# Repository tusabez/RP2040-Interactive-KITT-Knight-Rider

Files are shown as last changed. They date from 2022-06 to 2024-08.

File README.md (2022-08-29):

# RP2040-Interactive-KITT-Knight-Rider
Create your own KITT from the TV show Knight Rider using an RP2040 Microcontroller  <br />
YouTube video preview  <br />
<div align="center">
  <a href="https://www.youtube.com/watch?v=hxRDTuXU2fs">IMAGE ALT TEXT</a>
</div>

## Introduction
Welcome to the tutorial to build your very own Interactive KITT from the TV show Knight Rider!  This will be divided into 3 parts.  Part 1 will explain the hardware and PCBs needed for the project. <br />
Part 2 will explain the code and software needed to install on your RP2040 microcontroller. <br />
Part 3 will explain the asthetics including 3D printing the body, creating the labels for the indicators, and using colored sheets for the voicebox and indicators. <br />

# Part 1 Hardware
For this project, you will need to order 2 different PCBs to create KITT.  The Gerber files needed to have them made are available in this repository.  You will need to upload these files (two files already in zip format) to your preferred PCB manufacturer.  I usually use JLBPCB as they tend to be the cheapest but feel free to use anyone. <br />
You will also find a PDF called Parts which you can download and view. I'm not affiliated with any of the links.  They are there for your reference. You'll need these parts to complete the PCBs.  Note that you should be comfortable in soldering as there are many components needed to be soldered onto the boards. Most of these parts can be ordered through websites like Adafruit, Amazon, Aliexpress, Mouser, etc... <br />
## Equipment
For equipment needed to build this part of the project, you'll need a soldering iron and stand, hot air gun, some shrink wrap for wires, wire cutters and wire stripper, solder, and solder paste. <br />
## Parts
One part that is required for this project but no longer manufactured by Adafruit is the UDA1334A DAC module.  However, you can find 3rd party versions of it on Amazon and Aliexpress. <br />
The PDM Mic used for this project is very sensitive and I had difficulty making it detect sound correctly.  If you have this issue, try disconnecting the VCC(power) from the board to the mic and run it that way.  That seems to fix the problem and I'm not sure why. <br />
Notice the connectors between the two boards are 2mm and not the standard 2.54mm.  I'd like to say this was intentional to save room but honestly it was a mistake I made in the original design but I decided to keep it as it does make the cables a little more compact. <br />
The RGB LEDs used for the indicator lights (Not the LED bars for KITT) are 5v versions.  Make sure you check before you buy as they also make them in 12v. (I ended up getting shipped the wrong voltage LEDs and it took me a few weeks of troubleshooting before I figured out why my LED board didn't work.) <br />
I chose the Waveshare RP-2040 Plus microcontroller because it has 4MB of memory.  However, you can use any rp2040 based microcontroller as long as it has (A) 4MB or more of flash memory and (B) it is in the same form factor as the original Raspberry Pi Pico.  If you decide to go with a different microcontroller, make sure the pins line up exactly as the Pico with the same GPIO assignments or it will not work. <br />
## Part 1 video
<div align="center">
  <a href="https://www.youtube.com/watch?v=F8oxOOc2xko">IMAGE ALT TEXT</a>
</div>

# Part 2 Programming and Software
Coming soon <br />
# Part 3 Aesthetics and 3D printing
Coming soon

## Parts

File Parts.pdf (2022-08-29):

# LED Board Quantity Notes and Links

I'm not affiliated nor compensated for any of these links. These are for reference only. I recommend you shop around for the best deals.
100nf smd capacitor | 17 | https://www.amazon.com/100pcs-0805-100nf-Multilayer-Ceramic-Capacitor/dp/B07P9D6W78
10 segment LED Bar Red | 6 | https://www.mouser.com/ProductDetail/Kingbright/DC10SRWA?qs=SxaZfIVsCL3oiC6rI9sPSQ%3D%3D
WS2812B RGB LEDs | 17 | https://www.amazon.com/Led-World-WS2812B-Individually-Addressable/dp/B00YC7ZXRM
2mm headers | 1 | https://www.adafruit.com/product/2671
180 Ohms resistor | 6 | https://www.amazon.com/Projects-Resistors-Watt-Choose-Quantity/dp/B077H1VK2Z
150 Ohms resistor | 2 | https://www.amazon.com/Projects-Resistors-Watt-Choose-Quantity/dp/B072F77NL5

# Driver Board

Waveshare RP2040-Plus | 1 | https://www.waveshare.com/rp2040-plus.htm
10uF Tan Capacitor | 2 | https://www.amazon.com/CAPACITOR-SOLID-TANTALUM-10UF-RADIAL/dp/B007Z7PJT8
10uF Capacitor | 1 | https://www.amazon.com/Projects-Radial-Electrolytic-Capacitor-10uF/dp/B07YBCF9NG
1N5817 Diode | 1 | https://www.amazon.com/1N5817-Axial-Leaded-Schottky-Rectifier/dp/B00I6IDW30
AMS1117-1.8 | 1 | https://www.amazon.com/AMS1117-1-8V-AMS1117-Voltage-Regulator-SOT-223/dp/B07Q3D77KT
UDA1334A DAC | 1 | https://www.amazon.com/AITRIP-CJMCU-1334-UDA1334A-Decoder-Arduino/dp/B09DG21C7G
LM3915N-1 | 1 | https://www.amazon.com/LM3915N-LM3915-Nixie-Display-Driver/dp/B0137JYL00
IR Sensor | 1 | https://www.amazon.com/dp/B09WB54YSM
PDM Mic | 1 | https://www.adafruit.com/product/3492
2mm headers | 1 | same as above
Speaker Amp | 1 | https://www.adafruit.com/product/2130
12V Jack | 1 | https://www.amazon.com/DIKAVS-Breadboard-friendly-2-1mm-Barrel-Jack/dp/B074LK7G86
Power switch | 1 | https://www.amazon.com/DaierTek-250VAC-Rocker-KCD1-101-Plastic/dp/B07S2QJKTX
BC557 Transistors | 10 | https://www.amazon.com/Eowpower-250PCS-Values-Transistors-Assortment/dp/B071P849QB
1k Ohms Resistors | 11 | https://www.amazon.com/EDGELEC-Resistor-Tolerance-Resistance-Optional/dp/B07HDDWFDD
TSR 2-2450 | 1 | https://www.tracopower.com/model/tsr-2-2450
Variable Resistor | 1 | https://www.amazon.com/10K-OHM-Trimpot-Variable-Resistor/dp/B00YSMMCOI

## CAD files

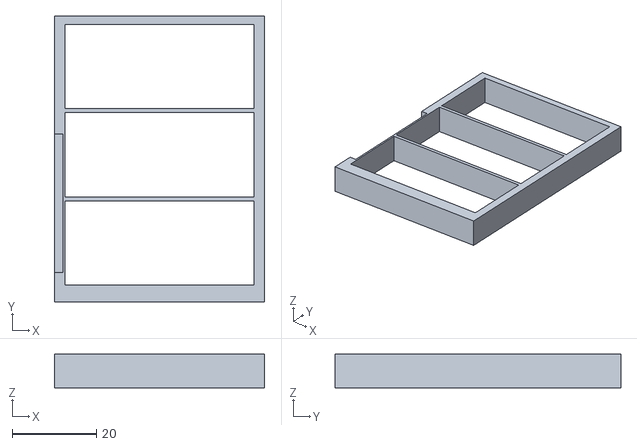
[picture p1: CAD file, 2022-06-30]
STLS/KITT Square Spacer v2.stl
50.0 x 68.0 x 8.00

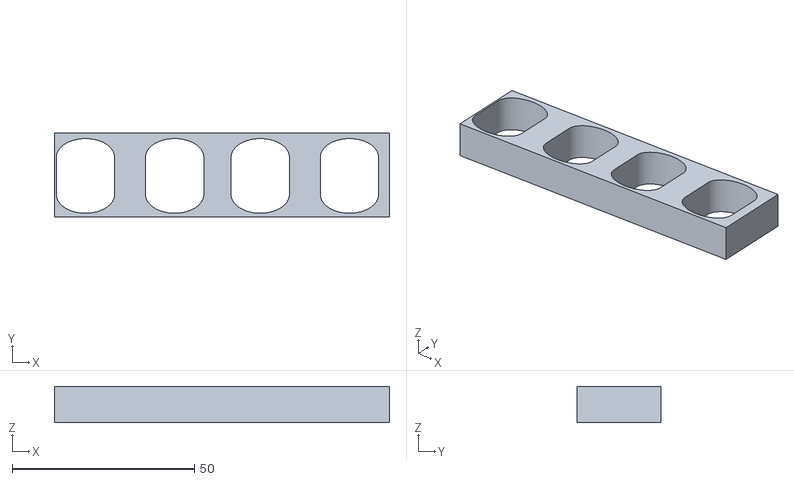
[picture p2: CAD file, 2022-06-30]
STLS/KITT Spacers x2.stl
92.0 x 23.0 x 10.00

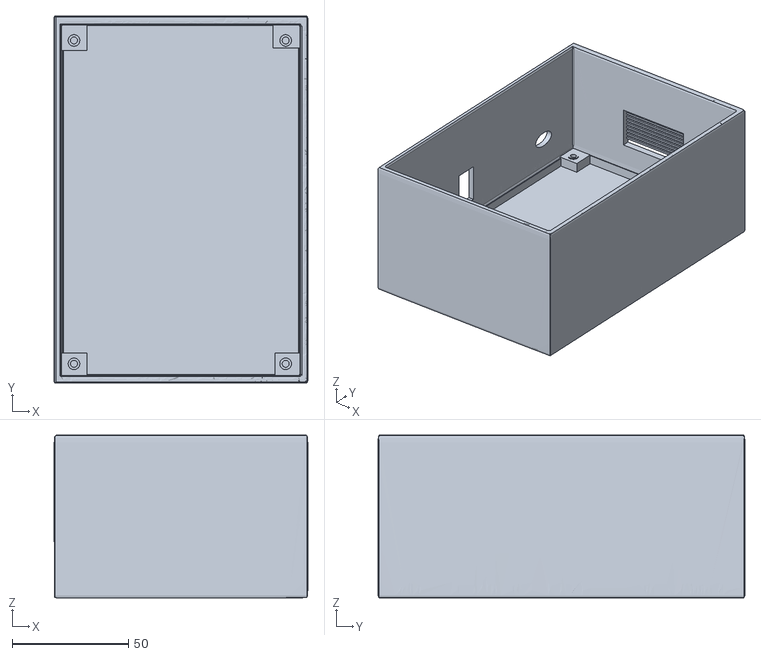
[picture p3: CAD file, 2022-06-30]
STLS/KITT Voice Box Backv3.stl
109.0 x 157.8 x 70.0

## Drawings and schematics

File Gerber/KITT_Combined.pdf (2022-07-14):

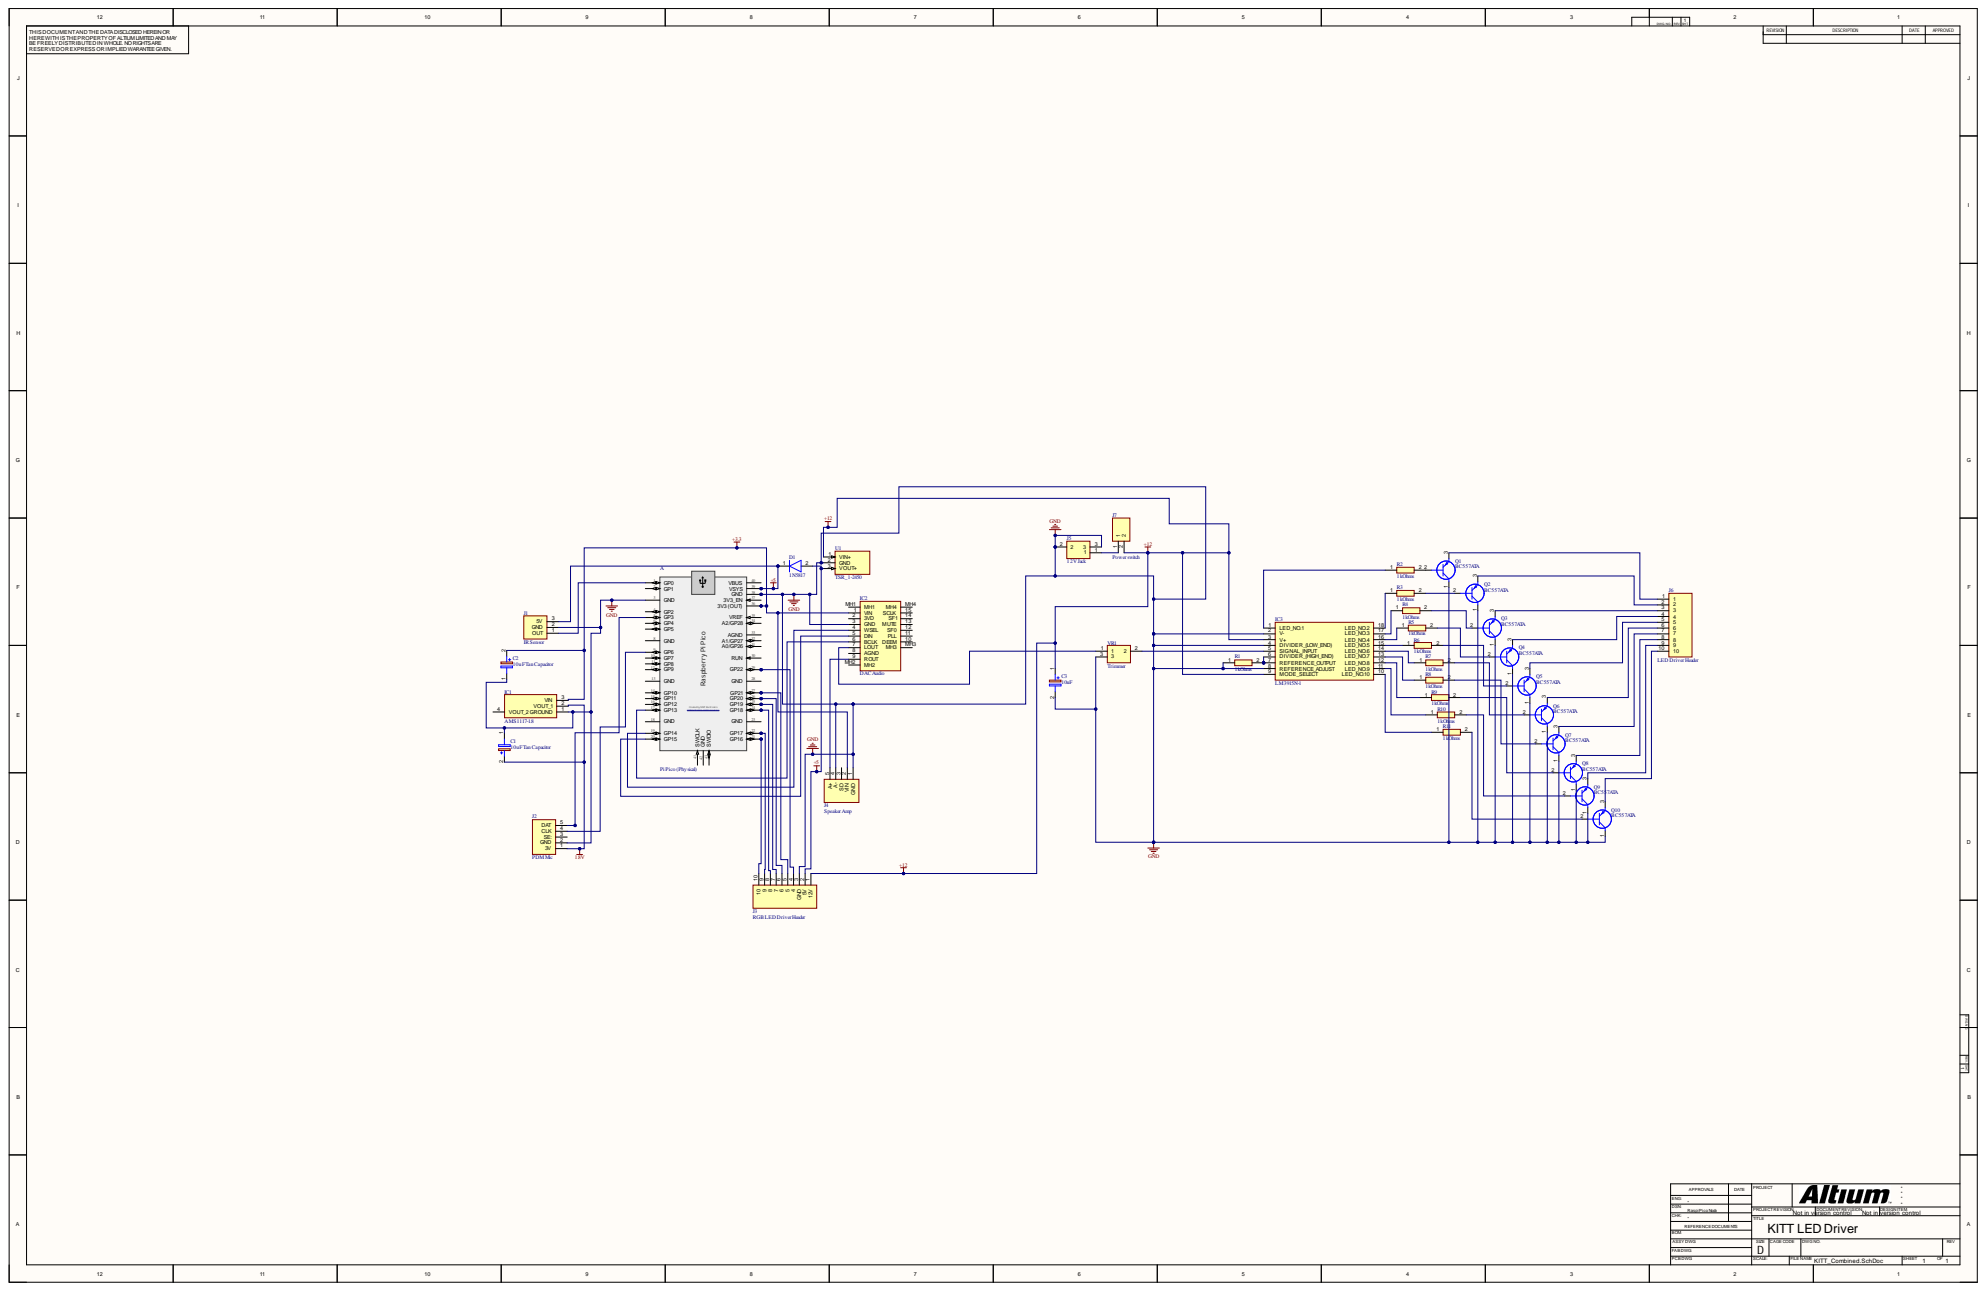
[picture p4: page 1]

T HEREW H IS DOC I T H U MEN IS T HE PROPER TAN D T HE D TY OFALTI ATA D I SC LOS U M E LI D M H I TE E R D E AN I N D O R M AY BE FREELY DISTRIBUTEDIN WHOLE. NO RIGHTS ARE RESERVEDOREXPRESS ORIMPLIED WARANTEE GIVEN. | R E VI S I ON D E S C R I PTI ON D ATE APPR OVE D

AREV. SHT. DWG.NO.

A P PRO VALS | DAT E | PRO J E CT | ****
DS N : Ra s p i P i c o Noob CHK : RE F ERENCE DOCUM | E NTS | PRO J ECTRE VISIO N : DOCUM ENTRE VISIO N : DE SIGN IT E M : TIT L E N o t i n ve rsi o n co n t r o l N o t i n ve rsi o n co n t r o l KITT LED Dri v e r

ENG : *

A S S Y DW G: | SIZ E D | CA G E CODE | DW G NO . | RE V

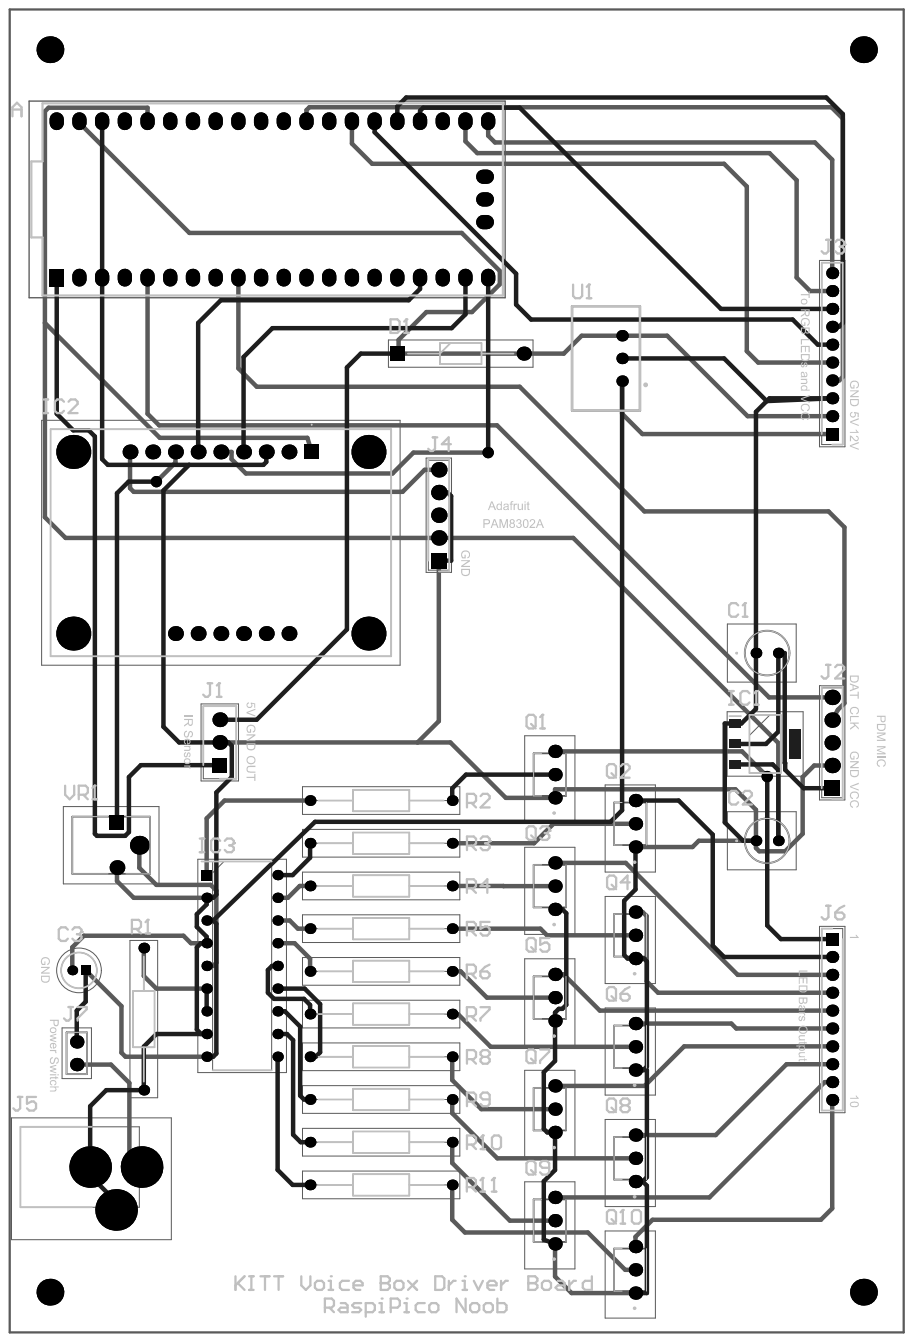
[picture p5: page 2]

Comment | Description | Designator | Footprint | LibRef | Quantity
Pi Pico (Physical) | Dual-Core RP2040-Based Microcontroller Board | A | Raspberry-Pi-Pico (THT, On Headers) | Raspberry-Pi-Pico-Physical | 1
10uF Tan Capacitor | Capacitor Polarised | C1, C2 | TAP106M016DCS | TAP106M016DCS | 2
10uF | Capacitor Polarised | C3 | CAPPRD150W50D400 H600 | ECE-A1CKS100 | 1
1N5817 | Diode | D1 | DIOAD1405W86L465 D235 | 1N5817 | 1
AMS1117-1.8 | Integrated Circuit | IC1 | SOT229P700X180-4N | AMS1117-1.8 | 1
DAC Audio | Integrated Circuit | IC2 | 3678 | 3678 | 1
LM3915N-1 | Integrated Circuit | IC3 | DIP794W56P254L228 6H533Q18N | LM3915N-1 | 1
IR Sensor | IR Sensor | J1 | HDRV3W63P0X254_1 X3_762X369X950P | 825433-3 | 1
PDM Mic | Connector | J2 | HDRV5W67P0X254_1 X5_1229X234X821P | 5-146280-5 | 1
RGB LED Driver Header | Connector | J3 | HDRV10W50P12X200 _1X10_2000X218X525 P | M22-2011005 | 1
Speaker Amp | Connector | J4 | HDRV5W67P0X254_1 X5_1229X234X821P | 5-146280-5 | 1
12V Jack | Connector | J5 | 1517620EE | 151-7620E-E | 1
LED Driver Header | Connector | J6 | HDRV10W50P12X200 _1X10_2000X218X525 P | M22-2011005 | 1
Power switch | Connector | J7 | 872242 | 87224-2 | 1
BC557ATA | Transistor BJT PNP | Q1, Q2, Q3, Q4, Q5, Q6, Q7, Q8, Q9, Q10 | BC33740TA | BC557ATA | 10
1kOhms | Resistor | R1, R2, R3, R4, R5, R6, R7, R8, R9, R10, R11 | RESAD1590W60L630D 240 | MFR-25FBF52-1K | 11
TSR_1-2450 | Undefined or Miscellaneous | U1 | TSR-1-24120 | TSR_1-2450 | 1
Trimmer | Variable Resistor | VR1 | N6L25T3N1033030 | N6L25T3N-103-3030 | 1

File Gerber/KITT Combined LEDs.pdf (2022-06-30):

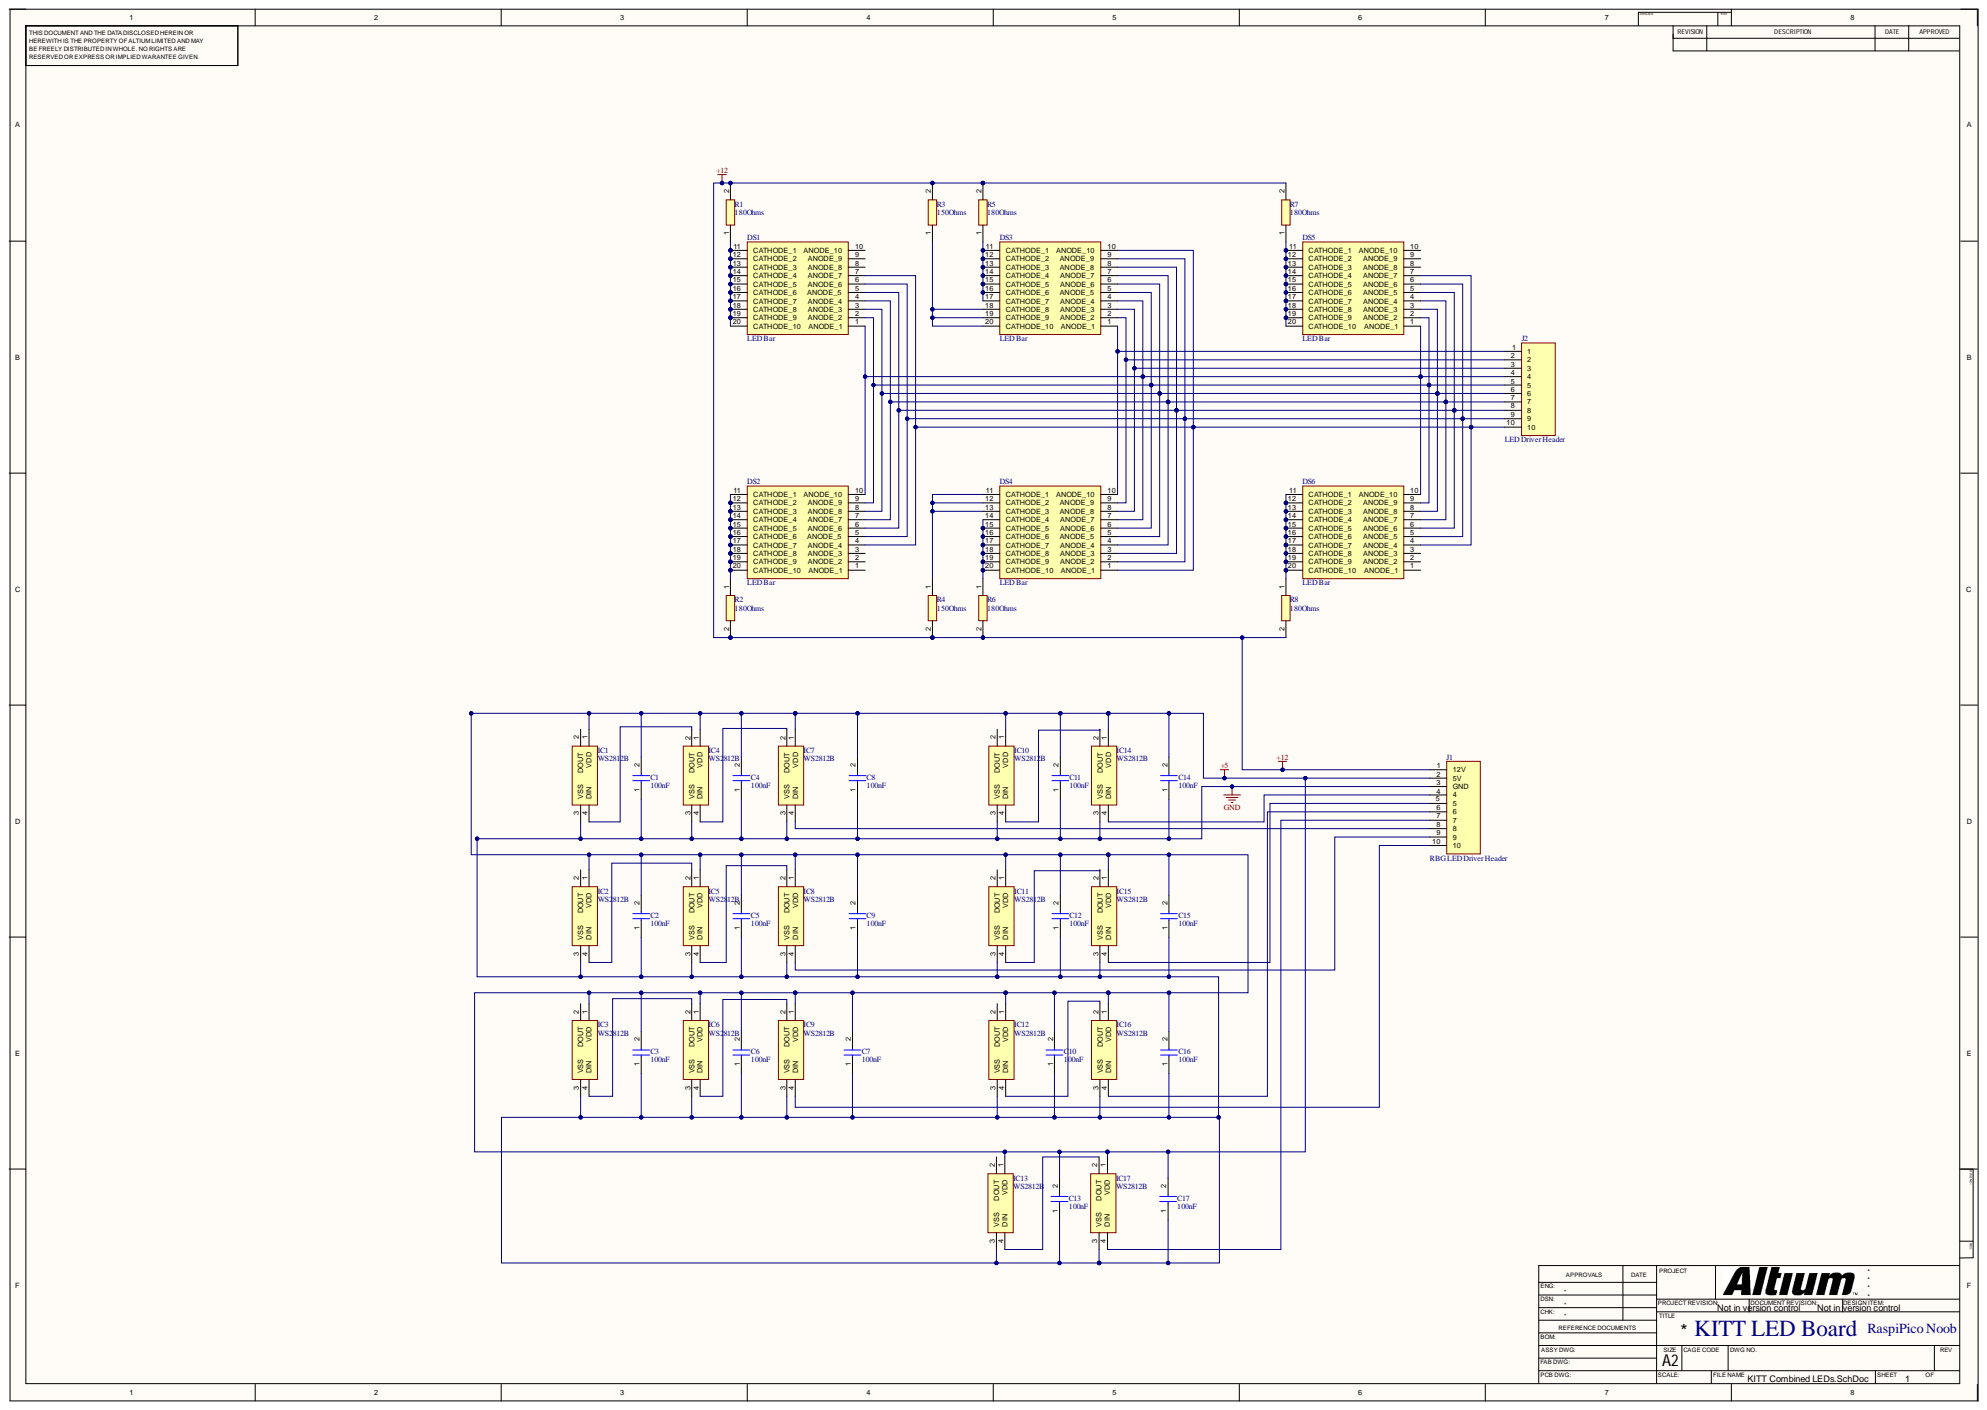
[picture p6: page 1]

1 | 2 | 3 | 4 | 5 | 6 | 7 | DWG NO: | REV: | 8

THIS DOCUMENT AND THE DATADISCLOSED HEREIN OR HEREWITH IS THE PROPERTY OF ALTIUM LIMITED AND MAY BE FREELY DISTRIBUTED IN WHOLE. NO RIGHTS ARE RESERVED OR EXPRESS OR IMPLIED WARANTEE GIVEN. | | REVISION | DESCRIPTION | DATE | APPROVED

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
10 10

GND 3

GND | | | 6 6

DATE | PROJECT | * * APPROVALS *

ENG: *
CHK: * | | TITLE * KITT LED Board RaspiPico Noob

DSN: * | | PROJECT REVISION: Not in version control | DOCUMENT REVISION: Not in version control | DESIGN ITEM:

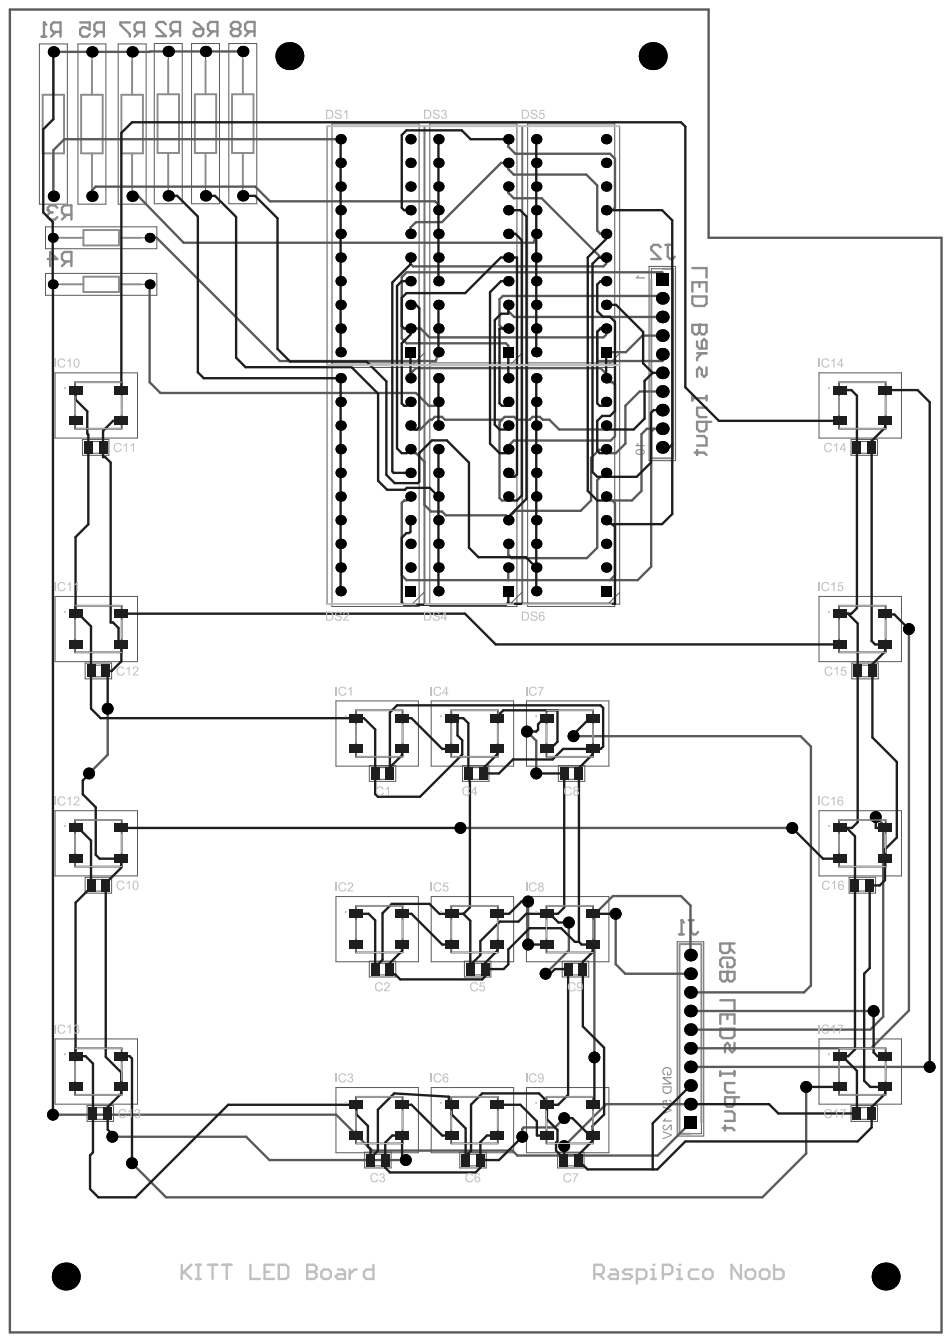
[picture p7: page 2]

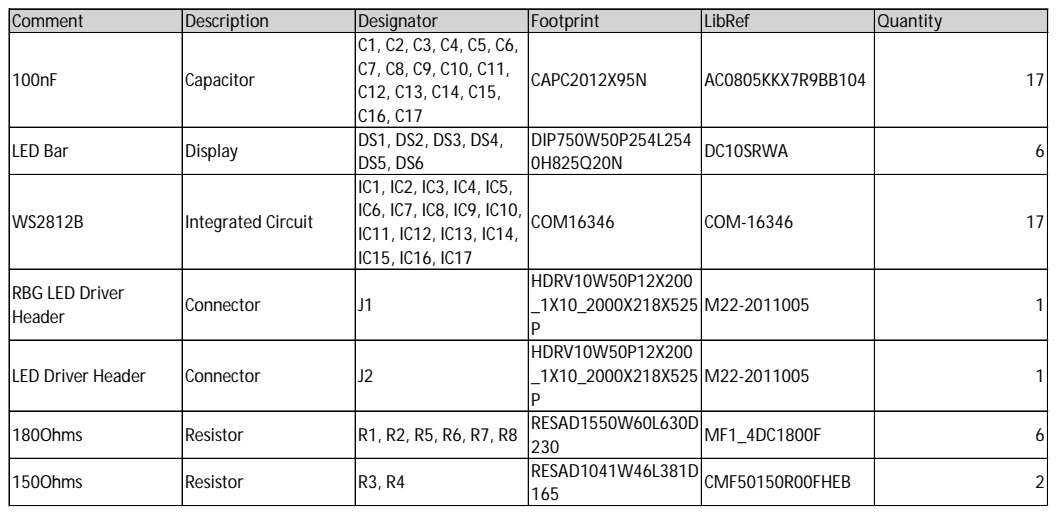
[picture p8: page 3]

Comment | Description | Designator | Footprint | LibRef | Quantity
100nF | Capacitor | C1, C2, C3, C4, C5, C6, C7, C8, C9, C10, C11, C12, C13, C14, C15, C16, C17 | CAPC2012X95N | AC0805KKX7R9BB104 | 17

LED Bar | Display | DS1, DS2, DS3, DS4, DS5, DS6 | DIP750W50P254L254 0H825Q20N | DC10SRWA | 6

WS2812B | Integrated Circuit | IC1, IC2, IC3, IC4, IC5, IC6, IC7, IC8, IC9, IC10, IC11, IC12, IC13, IC14, IC15, IC16, IC17 | COM16346 | COM-16346 | 17

RBG LED Driver Header | Connector | J1 | HDRV10W50P12X200 _1X10_2000X218X525 P | M22-2011005 | 1

LED Driver Header | Connector | J2 | HDRV10W50P12X200 _1X10_2000X218X525 P | M22-2011005 | 1

180Ohms | Resistor | R1, R2, R5, R6, R7, R8 | RESAD1550W60L630D 230 | MF1_4DC1800F | 6

150Ohms | Resistor | R3, R4 | RESAD1041W46L381D 165 | CMF50150R00FHEB | 2

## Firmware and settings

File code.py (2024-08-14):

# SPDX-FileCopyrightText: 2021 Kattni Rembor for Adafruit Industries
#
# SPDX-License-Identifier: MIT

"""
KITT interactive voice box by RaspiPico Noob
"""
import board
import audiomp3
import time
import array
import math
import audiobusio
import random
import digitalio
import neopixel # You'll need to get this module from CircuitPython library that matches the version of CircuitPython you are using. Make sure it's copied into your lib folder on your microcontroller.

#Defining IR Sensor pin
tracker = digitalio.DigitalInOut(board.GP0)
tracker.direction = digitalio.Direction.INPUT

# Remove DC bias before computing RMS.
def mean(values):
    return sum(values) / len(values)


def normalized_rms(values):
    minbuf = int(mean(values))
    samples_sum = sum(
        float(sample - minbuf) * (sample - minbuf)
        for sample in values
    )

    return math.sqrt(samples_sum / len(values))

mic = audiobusio.PDMIn(board.GP6, board.GP3, sample_rate=16000, bit_depth=16)
samples = array.array('H', [0] * 160)

audio = audiobusio.I2SOut(board.GP13, board.GP14, board.GP15)


#assigning KITT's dash indicator lights
first_row = neopixel.NeoPixel(board.GP22, 2)
second_row = neopixel.NeoPixel(board.GP21, 2)
third_row = neopixel.NeoPixel(board.GP20, 2)
fourth_row = neopixel.NeoPixel(board.GP19, 2)
auto_cruise = neopixel.NeoPixel(board.GP18, 3)
normal_cruise = neopixel.NeoPixel(board.GP17, 3)
pursuit = neopixel.NeoPixel(board.GP16, 3)


first_row.brightness = 0.25
second_row.brightness = 0.25
third_row.brightness = 0.25
fourth_row.brightness = 0.25
auto_cruise.brightness = 0.25
normal_cruise.brightness = 0.25
pursuit.brightness = 0.25

BLUE = (0, 0, 255)
RED = (255, 0, 0)
YELLOW = (255, 150, 0)
ORANGE = (255, 40, 0)

indicator = [1,2,3]

#list of mp3s to get KITT responding to sound. You can reorganize and add other lists as you wish
begin = ["I am the voice.mp3", "I am KITT.mp3", "I am a Knight Industries.mp3"]
intro = ["Hello!.mp3", "Not now, I have a headache.mp3", "Hello.mp3",  "You again_.mp3", "Im so glad to see you.mp3", "Perhaps I can be of some help.mp3", "Its good to hear your voice.mp3"]
middle = ["Ehum.mp3", "Good heavens! And I thought Michael was difficult.mp3", "I detect a certain tone in your voice.mp3", "How very unproductive.mp3", "I beg your pardon.mp3", "Surely youre not serious.mp3", "The things Im forced to put up with.mp3", "Well that's a new one.mp3", "Why_.mp3", "I dont follow your logic.mp3", "Tell me about it.mp3", "You must be joking.mp3", "Based on what_.mp3", "Easy for you to say.mp3"]
answer = ["Definitely possible.mp3", "I certainly hope so.mp3", "I suppose so.mp3", "I think so.mp3", "If you say so.mp3", "Of course.mp3", "Probably.mp3", "Im afraid so.mp3", "I cant believe its a real possibility.mp3", "I certainly hope not.mp3", "I dont think so.mp3", "In a word, no.mp3", "Im afraid not.mp3", "Negative.mp3", "Not a chance.mp3", "Not exactly.mp3", "Not to my knowledge.mp3", "My databanks have nothing on it.mp3", "I dont understand.mp3", "I have no idea.mp3", "If you say so.mp3"]
greeting = ["Sometimes I wonder if you really need me.mp3", "Your palms are clammy.mp3","Are you alright1.mp3", "Are you alright2.mp3","You've probably begun.mp3", "Youre awfully quiet.mp3", "Where are your pants_.mp3", "Next time you want something handled in a specific way.mp3", "My sensors.mp3", "Did you hear that_.mp3", "How much longer will we be staying here_.mp3", "How are you feeling_.mp3", "Deafness.mp3", "Can I be of assistance_.mp3", "Can a Rolls-Royce do computer scans_.mp3", "Bon voyage.mp3","I'm sorry I try.mp3","Are you there....mp3","As a machine.mp3"]
joke = ["I stopped for gas the other day....mp3", "When I was a kid....mp3", "What do you think.mp3", "Im definitely dark and handsome....mp3", "Im the Knight Industries Two Thousand, sure enough.mp3"]
thanks = ["De nada.mp3", "Dont mention it.mp3"]

sound = open(greeting[0], "rb")
initial = time.monotonic()
decoder = audiomp3.MP3Decoder(sound)
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

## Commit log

2022-06-30 Create stl
2022-06-30 KITT Voice Box Enclosure
    [KITT Voice Box Backv3.stl]
2022-06-30 Gerber files
2022-07-14 Updated Schematic and Gerber files
2024-08-13 Delete neopixel.mpy
    Use current version of Circuitpython library.
